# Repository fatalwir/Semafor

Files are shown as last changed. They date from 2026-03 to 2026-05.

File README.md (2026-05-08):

# Semafor
Jednoduchá stavebnice automatického dopravního semaforu

[Online náhled desky na KiCanvas.org](https://kicanvas.org/?repo=https%3A%2F%2Fgithub.com%2Ffatalwir%2FSemafor)

[Seznam součástek na TME.eu pro 200 kusů](https://www.tme.eu/cz/favourites/2ed6fcd7833b3872591e10073693d59d27b82430)

## Dokumentace

[📄 Dokumentace](https://github.com/fatalwir/Semafor/raw/main/dokumentace/navod_semafor.pdf) 

[🔗 Obvodová simulace: https://is.gd/taOPdk](https://www.falstad.com/circuit/circuitjs.html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)

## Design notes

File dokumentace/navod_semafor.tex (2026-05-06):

\documentclass[a4paper,12pt]{article}

\usepackage[utf8]{inputenc}
\usepackage[T1]{fontenc}
\usepackage[czech]{babel}
\usepackage[scaled]{helvet}
\renewcommand{\familydefault}{\sfdefault}
\usepackage{graphicx}
\usepackage{hyperref}
\usepackage{geometry}
\usepackage{booktabs}
\usepackage{float}
\usepackage{wrapfig}
\usepackage{fancyhdr}
\usepackage{qrcode}
\usepackage{xcolor}
\usepackage{csquotes}

\geometry{margin=1cm, top=2.5cm, headheight=1.5cm, headsep=0.3cm}

\pagestyle{fancy}
\fancyhf{}
\fancyhead[L]{}
\fancyhead[C]{{\Huge\textbf{\textit{Semafor}}}}
\fancyhead[R]{{\begingroup\hypersetup{urlcolor=black}\qrcode[height=2cm]{https://raw.githubusercontent.com/fatalwir/Semafor/main/dokumentace/navod_semafor.pdf}\endgroup}}
\renewcommand{\headrulewidth}{0pt}

\hypersetup{
    colorlinks=true,
    linkcolor=blue,
    urlcolor=blue,
}

\title{Semafor návod}
\author{Ing. Ondřej Kolář}
\date{\today}

\setcounter{secnumdepth}{0}
\setlength{\parindent}{0pt}
\setlength{\parskip}{0.4em}

\begin{document}

\subsection{Popis zapojení}
Konstrukce světelného semaforu představuje jednoduchý způsob, jak realizovat sekvenční řízení s využitím minimálního počtu součástek. Zapojení vychází z integrovaného obvodu 4060, který v sobě kombinuje oscilátor a 14bitový binární čítač. Využitím dvou vhodně zvolených výstupů čítače vzniká čtyřstavový automat odpovídající jednotlivým fázím dopravního semaforu.

Výstupní LED diody jsou řízeny metodou tzv. \textit{charlieplexingu}, která umožňuje ovládat více diod pomocí menšího počtu výstupních vývodů. Jednotlivé stavy tak přímo určují, která kombinace diod bude v daném okamžiku svítit.

Ve stavech, kdy je aktivní žluté světlo, je navíc využita zpětná vazba, která dočasně zvyšuje frekvenci oscilátoru. Díky tomu trvá žlutá signalizace kratší dobu, podobně jako u skutečných semaforů.

\begin{center}
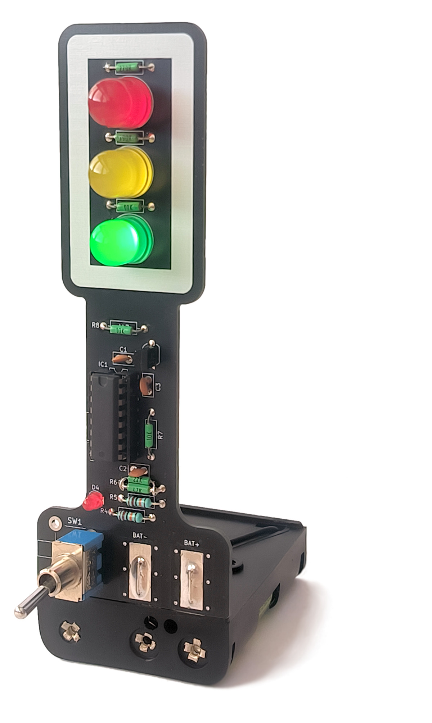
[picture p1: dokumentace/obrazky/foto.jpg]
    \hspace*{.1\textwidth}
\end{center}

\subsection{Postup oživení}
Na desku plošného spoje (DPS) nejprve osadíme rezistory, které jsou v několika různých hodnotách a je nutné dodržet jejich správné umístění. Poté připájíme tři keramické kondenzátory, které lze osadit ihned po rezistorech. Následuje tranzistor, u kterého je nutné dbát na správnou orientaci vyznačenou na DPS.

Dále osadíme integrovaný obvod 4060, kde je rovněž důležité dodržet správnou orientaci danou „vykousnutím“ na jednom okraji pouzdra. Na desku lze také připájet vypínač pro snadné zapínání a vypínání; pokud není osazen, je nutné propojit vyznačené pájecí plošky na zadní straně DPS.

Předposledním krokem je osazení LED diod. Ty musí být orientovány tak, aby kratší nožička (katoda), nacházející se u seříznuté hrany pouzdra, směřovala k dolnímu okraji DPS (do hranatého otvoru). Nakonec se připojí pouzdro pro tři AA baterie, které zároveň slouží jako podstavec zařízení.

\subsection{Sponzoři a podporovatelé}
\begin{tabular}{@{}ll@{}}

    Radioklub OK2KOJ při VUT v~Brně
        & \href{http://www.radio.feec.vutbr.cz/ok2koj/}{http://www.radio.feec.vutbr.cz/ok2koj/} \\

    FEKT VUT v~Brně, Ústav radioelektroniky
        & \href{https://www.urel.fekt.vut.cz/}{https://www.urel.fekt.vut.cz/} \\

\end{tabular}

\end{document}

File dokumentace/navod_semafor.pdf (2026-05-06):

# Semafor

### Popis zapojení

Konstrukce svetelného semaforu p ˇ | ˇredstavuje jednoduchý zp˚usob, jak realizovat sekvencní ˇ | ˇrízení s využitím
minimálního poctu sou ˇ | cástek. Zapojení vychází z integrovaného obvodu 4060, který v sob ˇ | e kombinuje os- ˇ
cilátor a 14bitový binární cíta ˇ | c. Využitím dvou vhodn ˇ | e zvolených výstup˚u ˇ | cíta ˇ | ce vzniká ˇ | cty ˇ ˇrstavový automat
odpovídající jednotlivým fázím dopravního semaforu.

Výstupní LED diody jsou ˇrízeny metodou tzv. charlieplexingu, která umožnuje ovládat více diod pomocí ˇ
menšího poctu výstupních vývod˚u. Jednotlivé stavy tak p ˇ | ˇrímo urcují, která kombinace diod bude v daném ˇ
okamžiku svítit.
Ve stavech, kdy je aktivní žluté svetlo, je navíc využita zp ˇ | etná vazba, která do ˇ | casn ˇ | e zvyšuje frekvenci osci- ˇ
látoru. Díky tomu trvá žlutá signalizace kratší dobu, podobne jako u skute ˇ | cných semafor˚u. ˇ

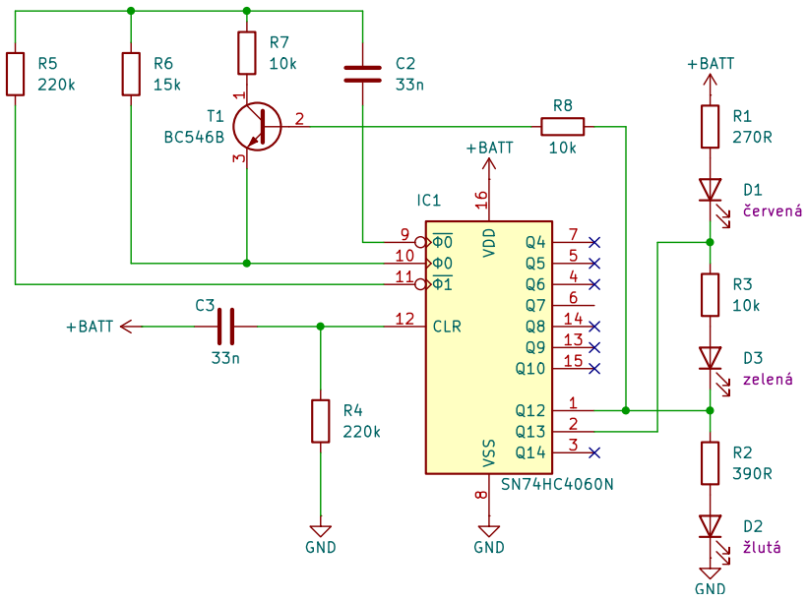
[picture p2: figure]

### Postup oživení


Na desku plošného spoje (DPS) nejprve osadíme rezistory, které jsou v nekolika r˚uzných hodnotách a je ˇ
nutné dodržet jejich správné umístení. Poté p ˇ | ˇripájíme tˇri keramické kondenzátory, které lze osadit ihned po
rezistorech. Následuje tranzistor, u kterého je nutné dbát na správnou orientaci vyznacenou na DPS. ˇ

Dále osadíme integrovaný obvod 4060, kde je rovnež d˚uležité dodržet správnou orientaci danou „vykousnu- ˇ tím“ na jednom okraji pouzdra. Na desku lze také pˇripájet vypínac pro snadné zapínání a vypínání; pokud ˇ
není osazen, je nutné propojit vyznacené pájecí plošky na zadní stran ˇ | e DPS. ˇ

Pˇredposledním krokem je osazení LED diod. Ty musí být orientovány tak, aby kratší nožicka (katoda), na- ˇ cházející se u seˇríznuté hrany pouzdra, smeˇˇrovala k dolnímu okraji DPS (do hranatého otvoru). Nakonec se
pˇripojí pouzdro pro tˇri AA baterie, které zároven slouží jako podstavec za ˇ | ˇrízení.

### Sponzori a podporovatelé ˇ

Radioklub OK2KOJ pˇri VUT v Brneˇ | http://www.radio.feec.vutbr.cz/ok2koj/
FEKT VUT v Brne, Ústav radioelektroniky ˇ | https://www.urel.fekt.vut.cz/

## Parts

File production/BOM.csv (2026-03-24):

Designator | Footprint | Quantity | Value | LCSC Part #
BAT+1 | SolderWire-0.5sqmm_1x01_D0.9mm_OD2.3mm | 1 | BH-331P24
C1, C2, C3 | C_Disc_D5.0mm_W2.5mm_P2.50mm | 3 | 33n
D1 | LED_D10.0mm | 1 | LL-1003VD2D-V1-1A
D2 | LED_D10.0mm | 1 | LL-1003UYD2D-Y2-1A
D3 | LED_D10.0mm | 1 | LL-1004PGD2R-G5-2B
D4 | LED_D3.0mm | 1 | LL-304VD2E-V1-1A
IC1 | DIP-16_W7.62mm_LongPads | 1 | 4060
R1 | R_Axial_DIN0207_L6.3mm_D2.5mm_P10.16mm_Horizontal | 1 | 270R
R2 | R_Axial_DIN0207_L6.3mm_D2.5mm_P10.16mm_Horizontal | 1 | 390R
R3, R7, R8, R9 | R_Axial_DIN0207_L6.3mm_D2.5mm_P10.16mm_Horizontal | 4 | 10k
R4, R5 | R_Axial_DIN0207_L6.3mm_D2.5mm_P10.16mm_Horizontal | 2 | 220k
R6 | R_Axial_DIN0207_L6.3mm_D2.5mm_P10.16mm_Horizontal | 1 | 15k
SW1 | EG1206A | 1 | E-SWITCH EG1206A
T1 | TO-92_Inline_Wide | 1 | BC546B

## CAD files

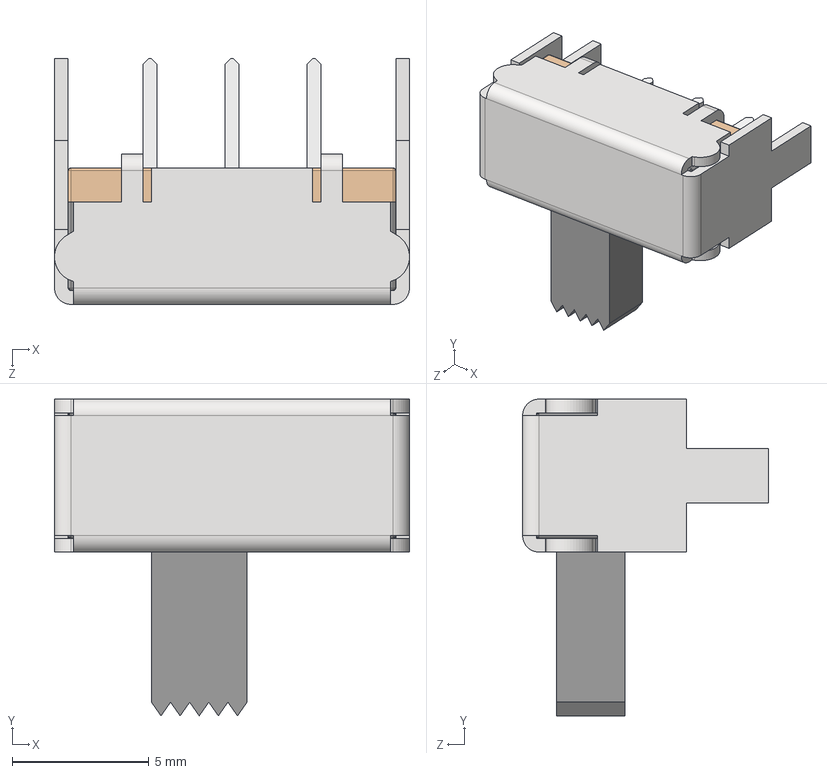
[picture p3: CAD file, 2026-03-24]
EG1206A.stp
13.0 x 11.6 x 9.00 mm

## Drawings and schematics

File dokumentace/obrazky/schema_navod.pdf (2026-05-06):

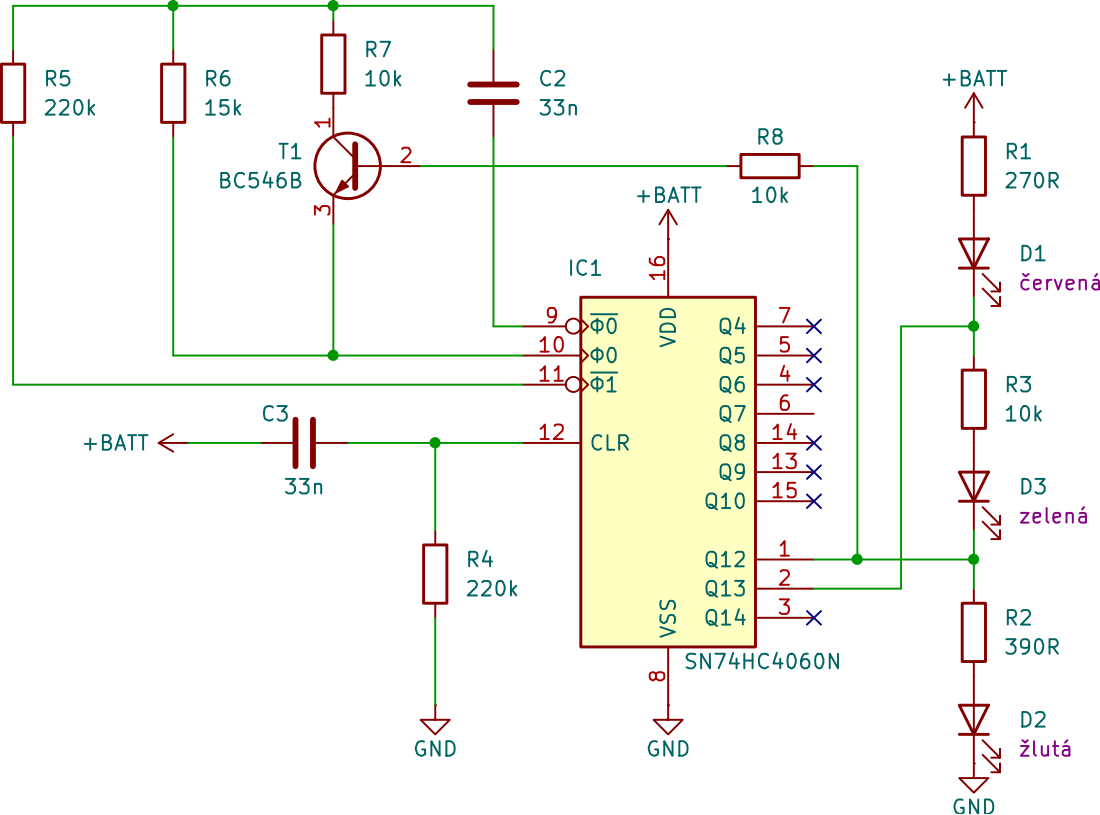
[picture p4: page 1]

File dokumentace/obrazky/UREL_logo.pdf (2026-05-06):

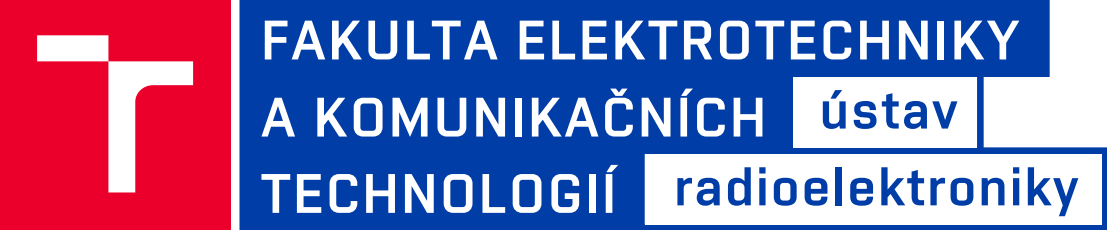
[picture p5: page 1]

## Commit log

2025-11-30 First schematic draft
    [Semafor.kicad_pcb, Semafor.kicad_sch]
2025-12-02 Hodnoty součástek
    [Semafor.kicad_sch]
2026-01-05 Finished Rev.0
    [Semafor.kicad_pcb, Semafor.kicad_sch]
2026-03-19 Rev.1: Modified some component values, polished silkscreen
    [Semafor.kicad_pcb, Semafor.kicad_sch]
2026-03-24 Finished Rev.1
    [EG1206A.stp, Semafor.kicad_pcb, Semafor.kicad_sch]
2026-03-24 Add logo to the PCB
    [Semafor.kicad_pcb]
2026-03-24 Add BOM.csv
    [BOM.csv]
